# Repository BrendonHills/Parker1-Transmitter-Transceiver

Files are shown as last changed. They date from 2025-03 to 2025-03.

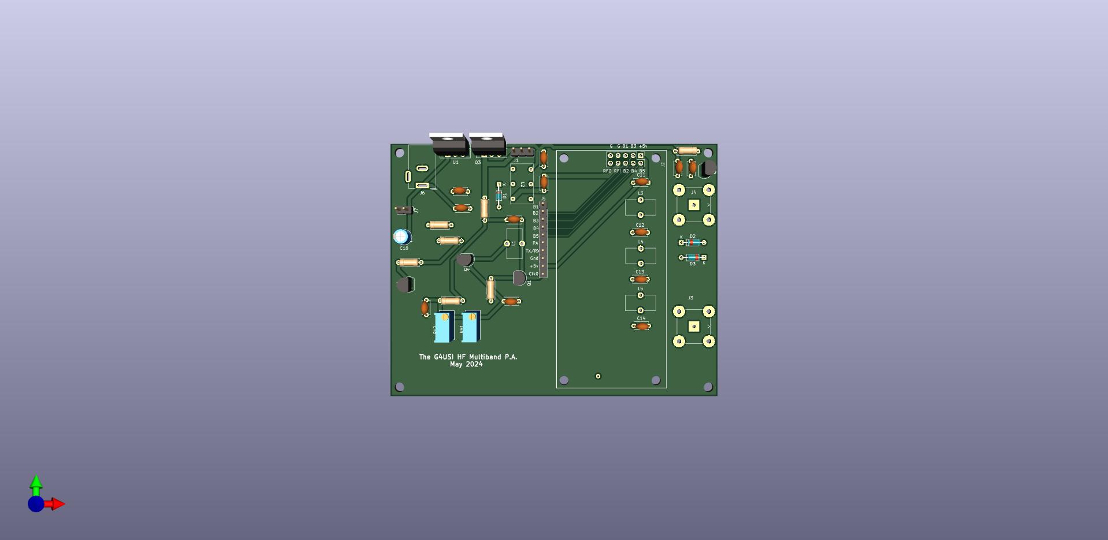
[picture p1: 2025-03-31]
HF PA multibandFront.jpg

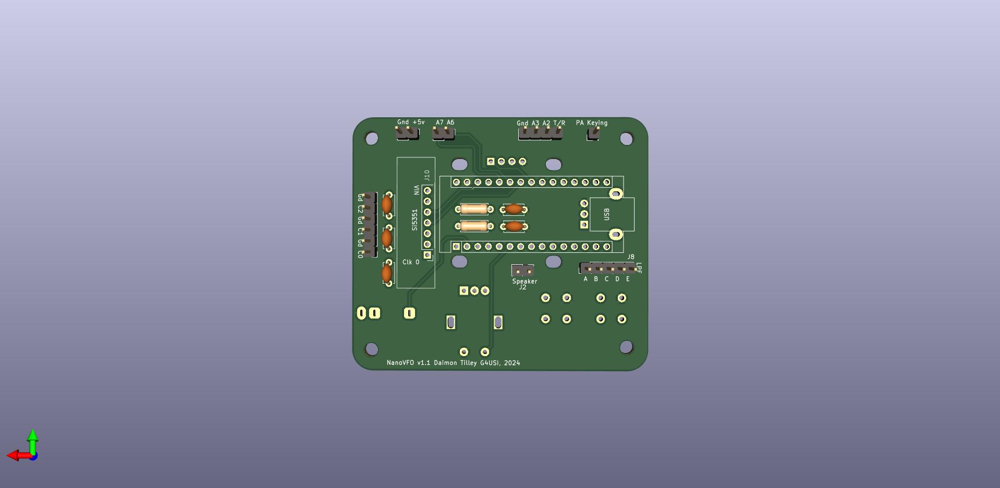
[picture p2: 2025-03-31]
NanoVFOpcbRear.jpg

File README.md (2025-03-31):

# The Parker1-Transmitter / Transceiver
The design of a ten band HF transmitter / transceiver and winner of the G-QRP Club Memorial Trophy 2024.

Please see the attached submission to the G-QRP Club for a full description of the project. Circuit diagrams and PCB files are in Ki-Cad 7.0
software and you may need to download that in order to view.

The transmitter consists of two parts, the Nano VFO and the HF Multi-band PA, connected together to make the transmitter. 
Note that the HF PA board is designed to have the QRPLabs LPF Relay board mounted on it to provide five LPFs covering ten bands (160-10m.)

Since this submission, the transmitter is now a transceiver, with the addition of a QRPLabs RX module, 
Hi-Per-Mite CW filter and audio amp. This is not protrayed in the diagrams here, but the circuit diagrams of the TX and VFO should make connections clear.
The L-Match ATU and internal battery pack are also not depicted, and there are no diagrams for this, but you should be able to work this out yourself.
All that is shown here is the code, circuit diagrams and PCB files for the VFO and for the PA board, nothing else,
however it is a great place to start and then experiment further.

I AM SORRY BUT I AM TOO BUSY TO OFFER SUPPORT OR ANSWER QUESTIONS (I have already answered a lot!) Please do not attempt this project without being
aware of that and reasonably confident in your abilities. My advice would to be just build the VFO first. The provided transceiver code will still work with just the VFO, but be aware that the code only activates the Si5351 clocks for TX and TX when those modes are in operation. In other words, to use just the VFO you would need to modify the clock output code to acheive a permanent clock / VFO output if that is what is required.

You will need to modify the code yourself to select your starting frequency and your callsign / CQ message. I have tried to make the code clear with plenty of remarks.
You will also need to amend the code to choose the RX frequency settings (i.e. offset, etc.) These options are NOT menu driven and must be done within the code
before uploading to the VFO. Therefore a degree of construction and programming experience is absolutely required.

The project has attracted quite a bit of interest since recently winning the G-QRP Club 2024 Construction Competition (G3RJV Trophy) and the intent
of this repository is to assist those interested in building it or using it as a platform for their own projects. I am sorry I am unable to help further but
hope this is of use.

Good luck.
Daimon, G4USI.

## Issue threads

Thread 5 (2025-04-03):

(Feature Request)- Create single document BOM for Parker1 Build

chrisdebian, 2025-04-03:
To help kit builders to compare local component prices, and to easily order items, the community should create a Bill of Materials (parts list) or BOM. Many examples exist of what to include in a BOM, and [this](https://www.proto-electronics.com/blog/how-to-create-best-bom-for-pcb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,could%20have%20a%20dedicated%20BOM.) is just one such example.

The file should be easily recognisable, including 'BOM-Bill of Materials' and any version numbers.

Chris
2E0FRU

chrisdebian, 2025-04-04:
I have found an example, [here](Example format from https://www.newburyelectronics.co.uk/news/free-bom-template-for-excel/). I can't upload this to the main project page, as I don't have 'push' access.

[pcb-bom-sample-file.xlsx](https://github.com/user-attachments/files/19602316/pcb-bom-sample-file.xlsx)

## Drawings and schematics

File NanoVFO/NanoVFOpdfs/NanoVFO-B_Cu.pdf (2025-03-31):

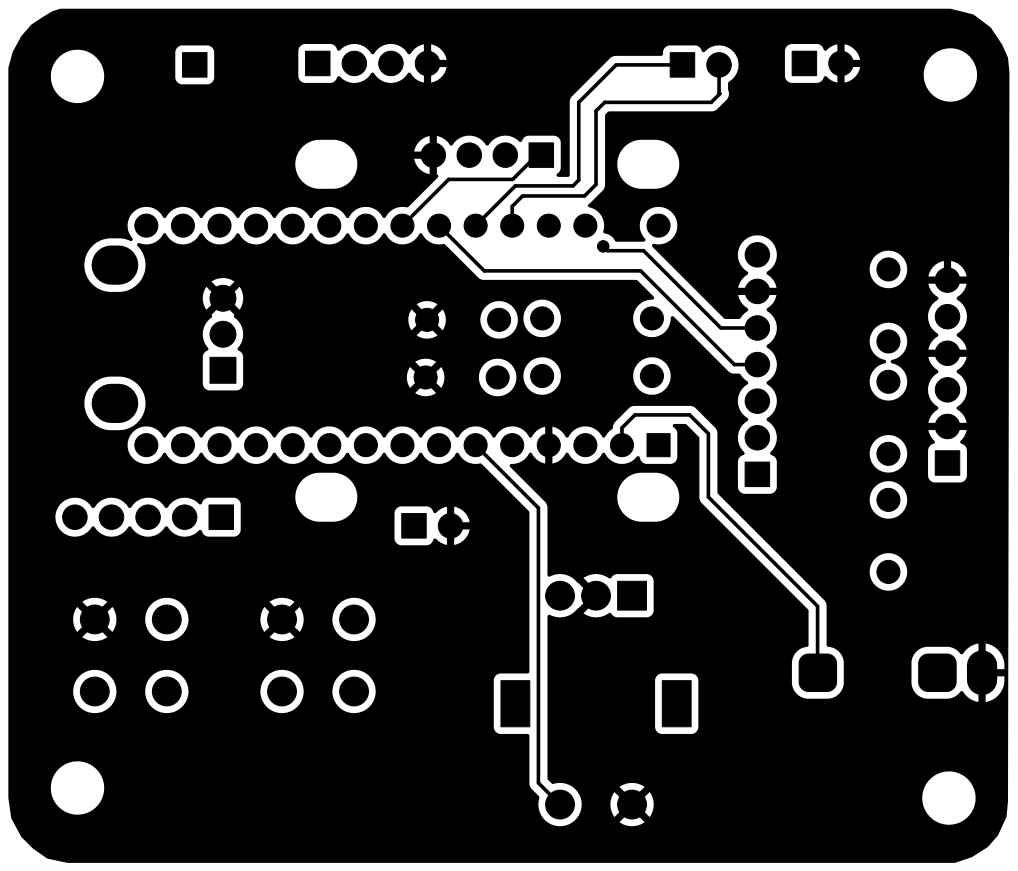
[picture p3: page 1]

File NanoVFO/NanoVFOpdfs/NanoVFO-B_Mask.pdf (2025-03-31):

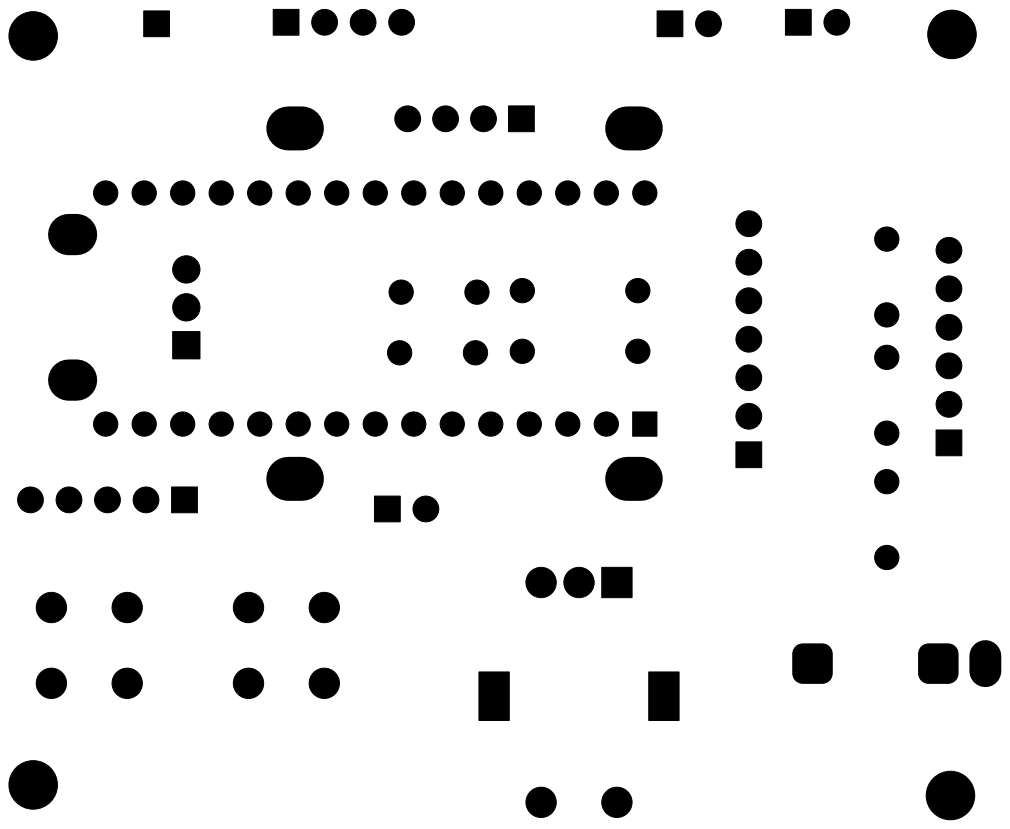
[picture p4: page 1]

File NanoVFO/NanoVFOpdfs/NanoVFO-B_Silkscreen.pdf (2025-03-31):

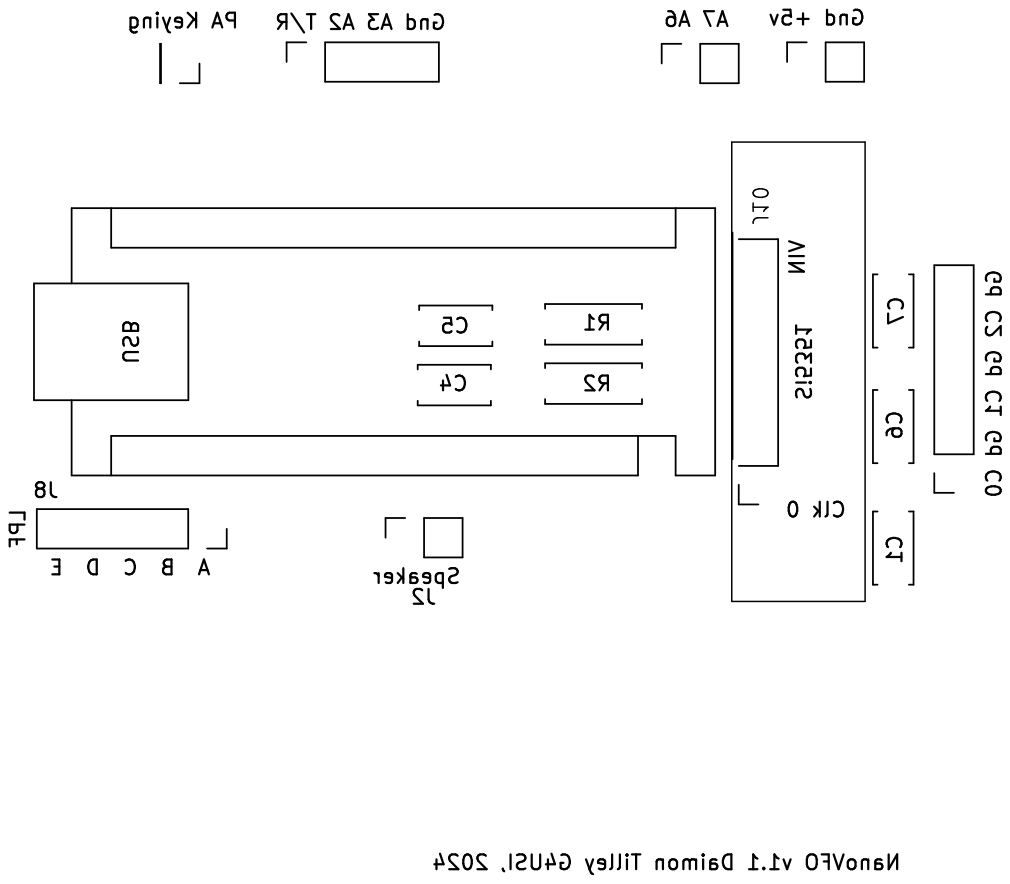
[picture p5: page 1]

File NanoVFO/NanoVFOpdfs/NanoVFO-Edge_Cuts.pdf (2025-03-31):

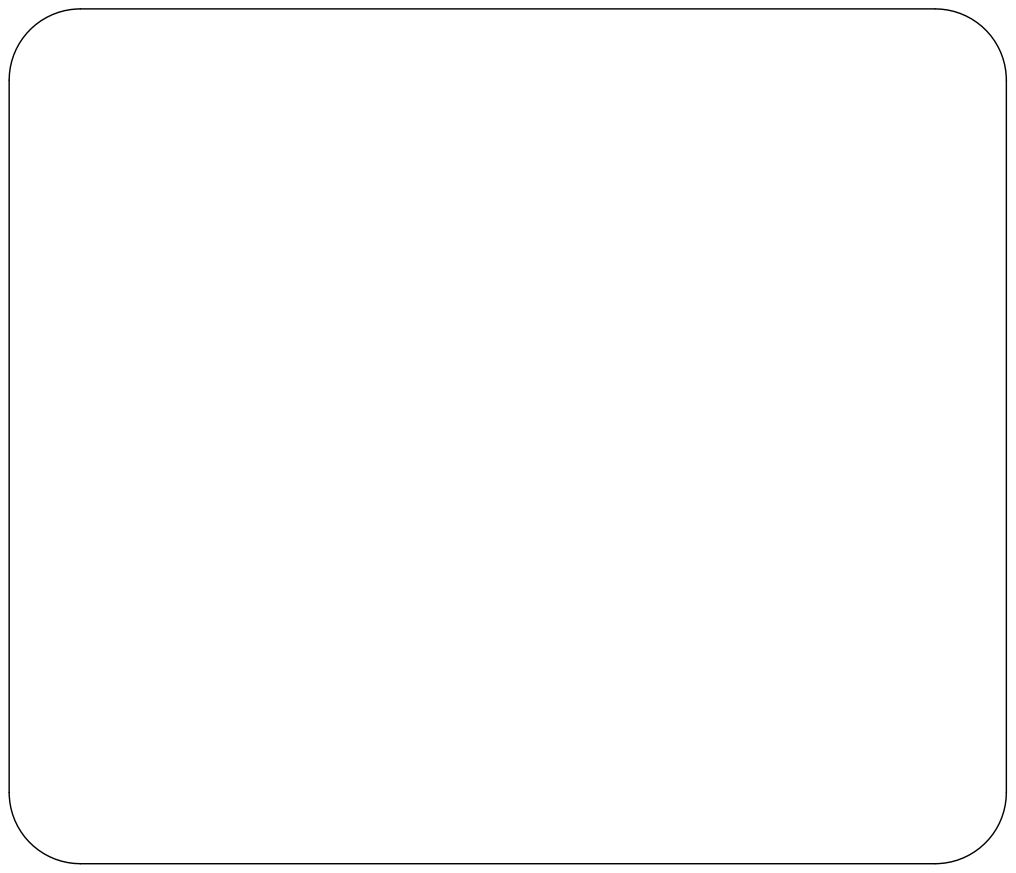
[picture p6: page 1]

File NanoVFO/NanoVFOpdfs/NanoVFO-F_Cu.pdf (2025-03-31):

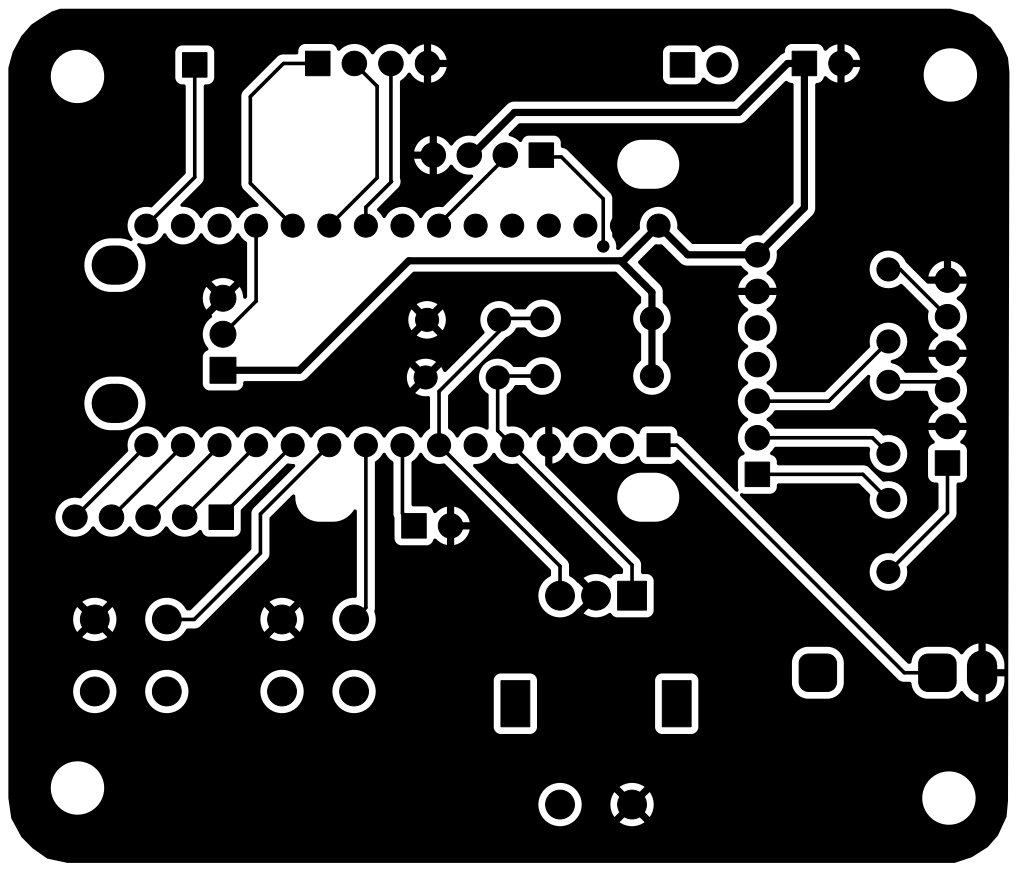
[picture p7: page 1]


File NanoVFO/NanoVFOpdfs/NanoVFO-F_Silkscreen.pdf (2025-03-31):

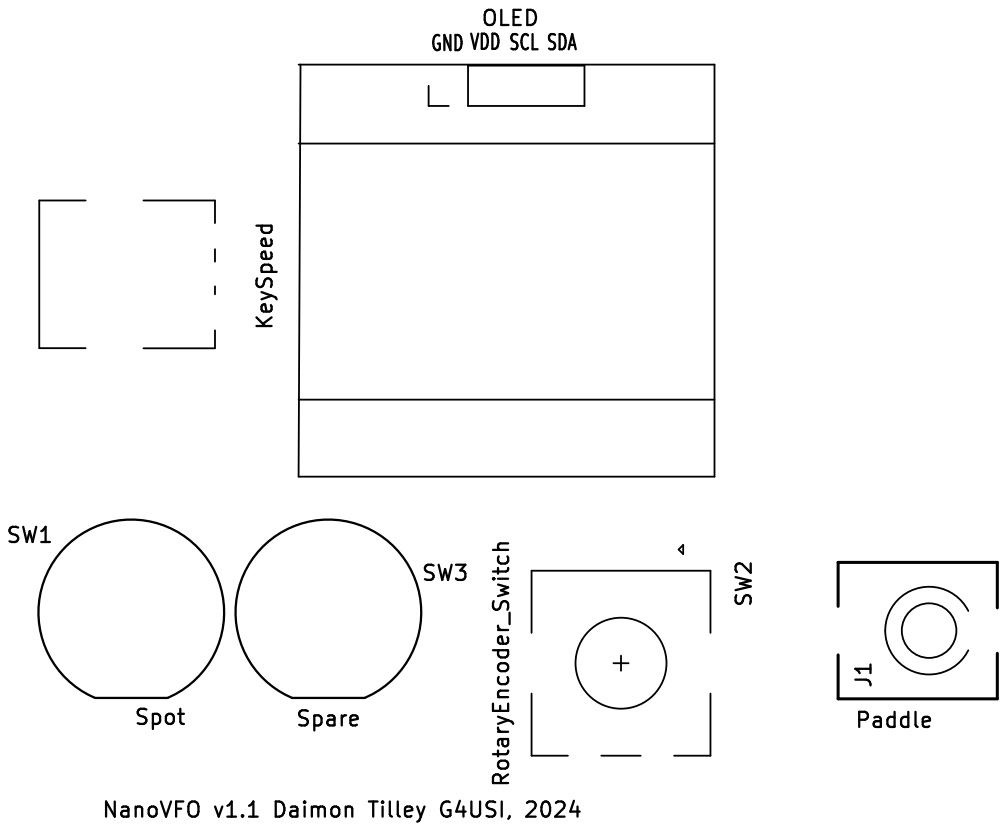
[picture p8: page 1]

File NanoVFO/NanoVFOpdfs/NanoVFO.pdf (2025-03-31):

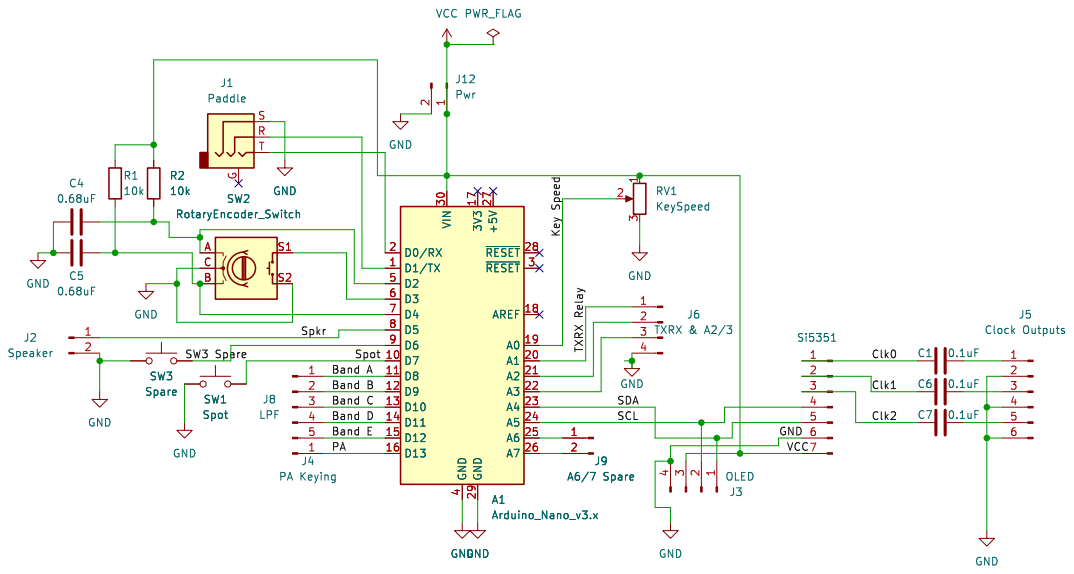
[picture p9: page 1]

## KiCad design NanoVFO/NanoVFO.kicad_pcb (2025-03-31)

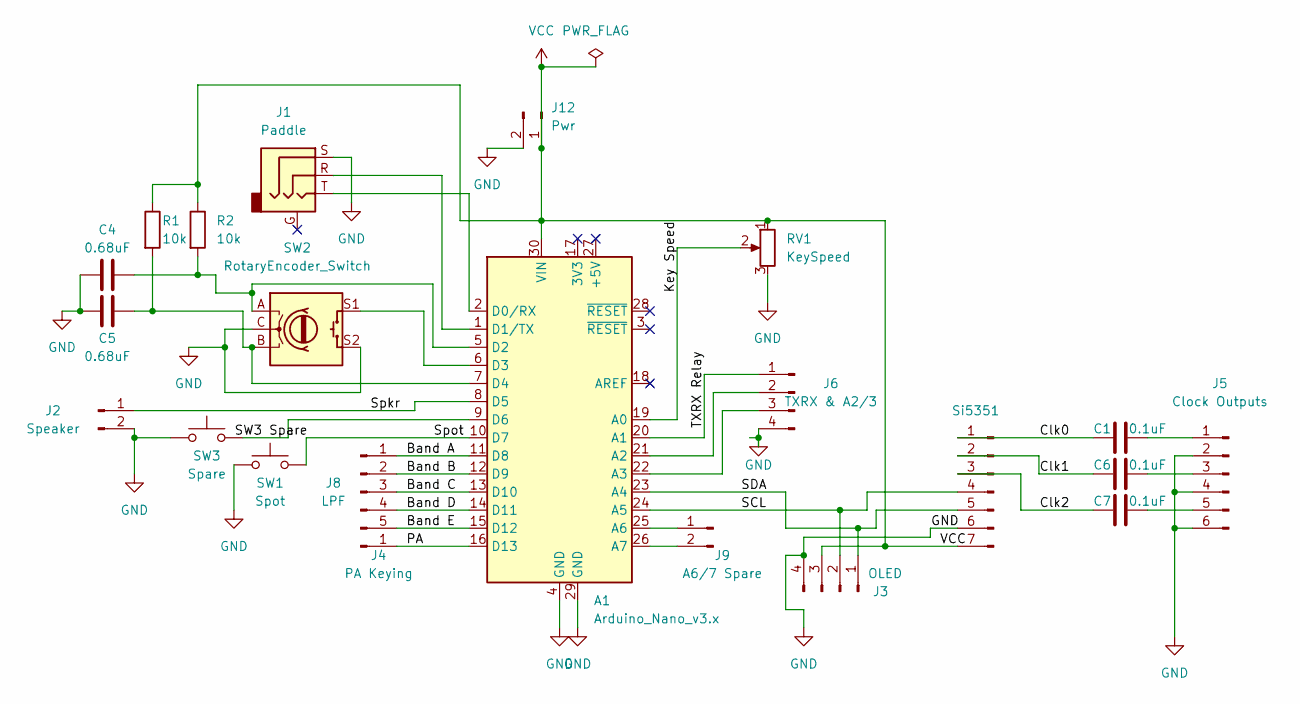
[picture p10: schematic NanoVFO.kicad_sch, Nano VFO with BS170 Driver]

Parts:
A1: Arduino_Nano_v3.x; Arduino_Nano
C1, C6, C7: 0.1uF; C_Disc_D4.7mm_W2.5mm_P5.00mm
C4, C5: 0.68uF; C_Disc_D4.7mm_W2.5mm_P5.00mm
J1: Paddle; Jack_3.5mm_QingPu_WQP-PJ366ST_Vertical
J2: Speaker; PinHeader_1x02_P2.54mm_Vertical
J3: OLED; Display_128x64_096_I2C
J4: PA Keying; PinHeader_1x01_P2.54mm_Vertical
J5: Clock Outputs; PinHeader_1x06_P2.54mm_Vertical
J6: TXRX & A2/3; PinHeader_1x04_P2.54mm_Vertical
J8: LPF; PinHeader_1x05_P2.54mm_Vertical
J9: A6/7 Spare; PinHeader_1x02_P2.54mm_Vertical
J10: Si5351; Si5351 Vertical
J12: Pwr; PinHeader_1x02_P2.54mm_Vertical
R1, R2: 10k; R_Axial_DIN0207_L6.3mm_D2.5mm_P7.62mm_Horizontal
RV1: KeySpeed; Potentiometer_Alpha_RD901F-40-00D_Single_Vertical
SW1: Spot; Push_E-Switch_KS01Q01
SW2: RotaryEncoder_Switch; RotaryEncoder_Alps_EC11E-Switch_Vertical_H20mm
SW3: Spare; Push_E-Switch_KS01Q01

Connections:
/Band A: A1.11 (D8), J8.1
/Band B: A1.12 (D9), J8.2
/Band C: A1.13 (D10), J8.3
/Band D: A1.14 (D11), J8.4
/Band E: A1.15 (D12), J8.5
/Clk0: C1.2, J10.1
/Clk1: C6.1, J10.2
/Clk2: C7.1, J10.3
/Key Speed: A1.19 (A0), RV1.2
/PA: A1.16 (D13), J4.1
/SCL: A1.24 (A5), J3.2, J10.4
/SDA: A1.23 (A4), J3.1, J10.5
/Spkr: A1.8 (D5), J2.1
/Spot: A1.10 (D7), SW1.2
/TXRX Relay: A1.20 (A1), J6.1
GND: A1.4 (GND), A1.29 (GND), C4.2, C5.2, J1.S, J2.2, J3.4, J5.2, J5.4, J5.6, J6.4, J10.6, J12.2, RV1.3, SW1.1, SW2.C, SW2.S2, SW3.1
unnamed: A1.21 (A2), J6.2
unnamed: A1.22 (A3), J6.3
unnamed: A1.25 (A6), J9.1
unnamed: A1.26 (A7), J9.2
unnamed: A1.2 (D0/RX), J1.T
unnamed: A1.1 (D1/TX), J1.R
unnamed: A1.5 (D2), C4.1, R2.2, SW2.A
unnamed: A1.6 (D3), SW2.S1
unnamed: A1.7 (D4), C5.1, R1.2, SW2.B
unnamed: A1.9 (D6), SW3.2
unnamed: C1.1, J5.1
unnamed: C6.2, J5.3
unnamed: C7.2, J5.5
VCC: A1.30 (VIN), J3.3, J10.7, J12.1, R1.1, R2.1, RV1.1

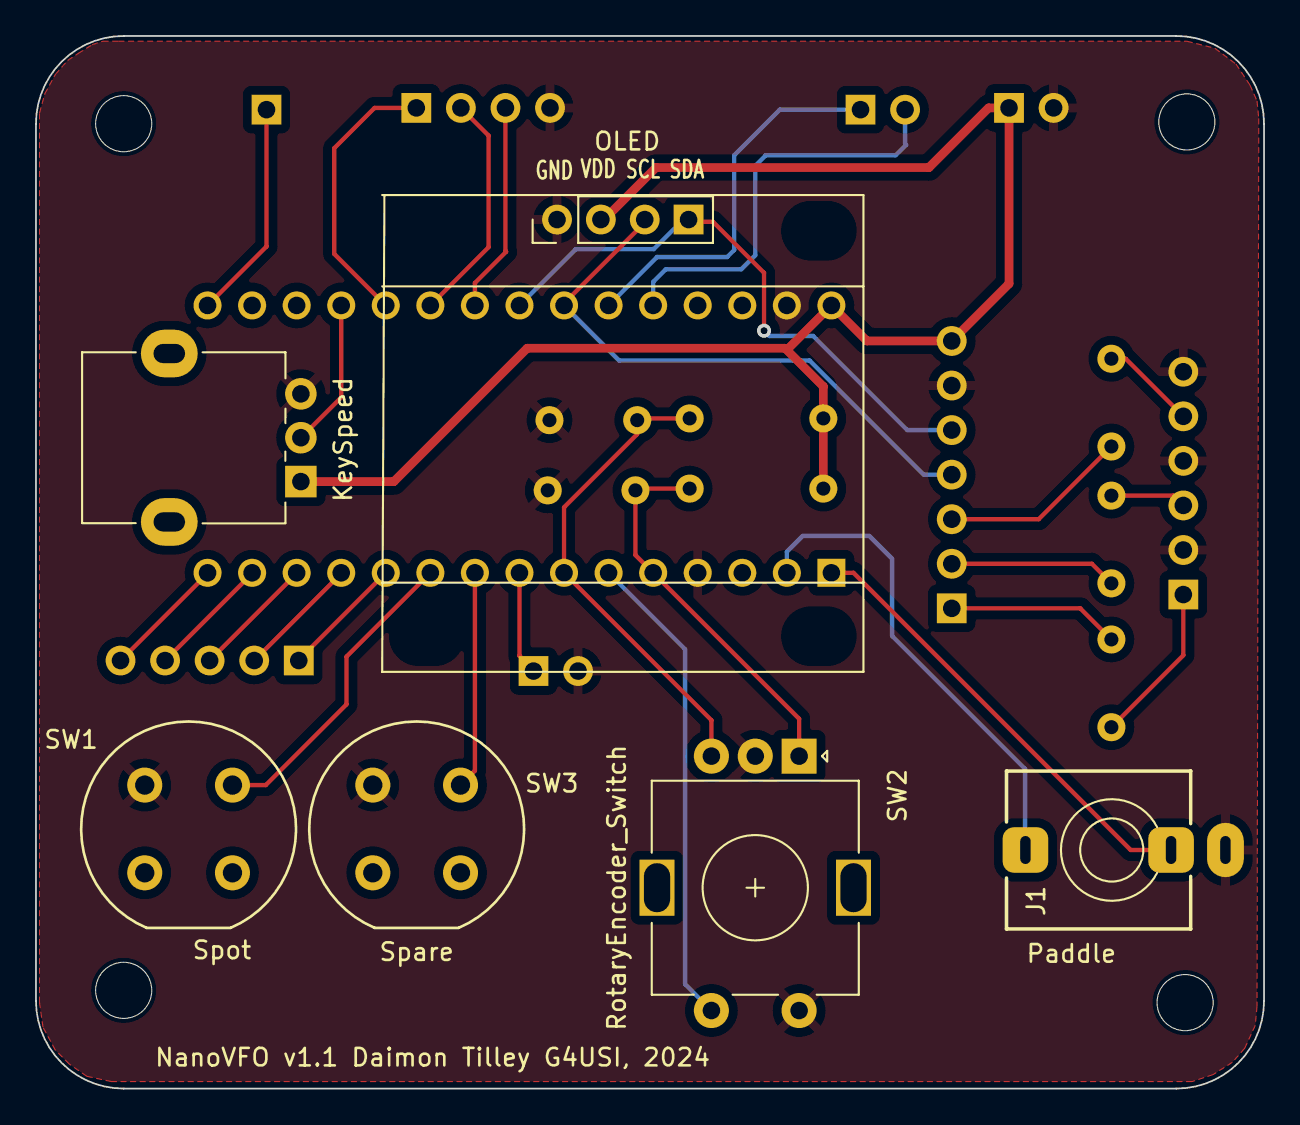
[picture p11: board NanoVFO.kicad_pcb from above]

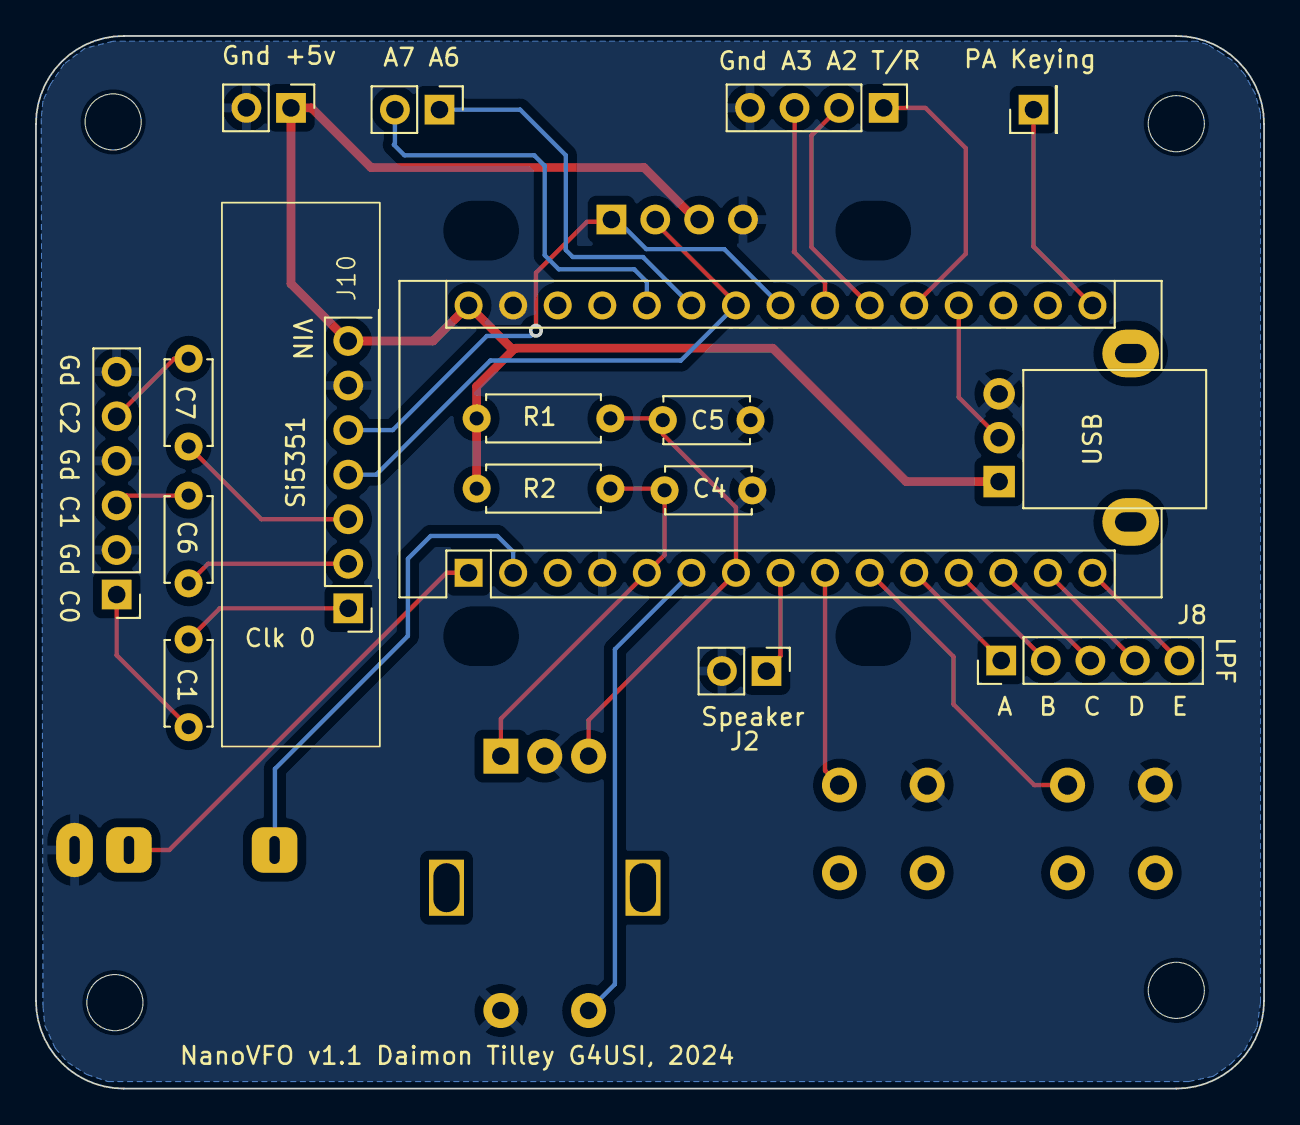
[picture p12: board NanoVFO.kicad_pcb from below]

Board: 2 copper layers, 70.0 x 60.0 mm, 22 parts (16 on the bottom side), 30 nets.

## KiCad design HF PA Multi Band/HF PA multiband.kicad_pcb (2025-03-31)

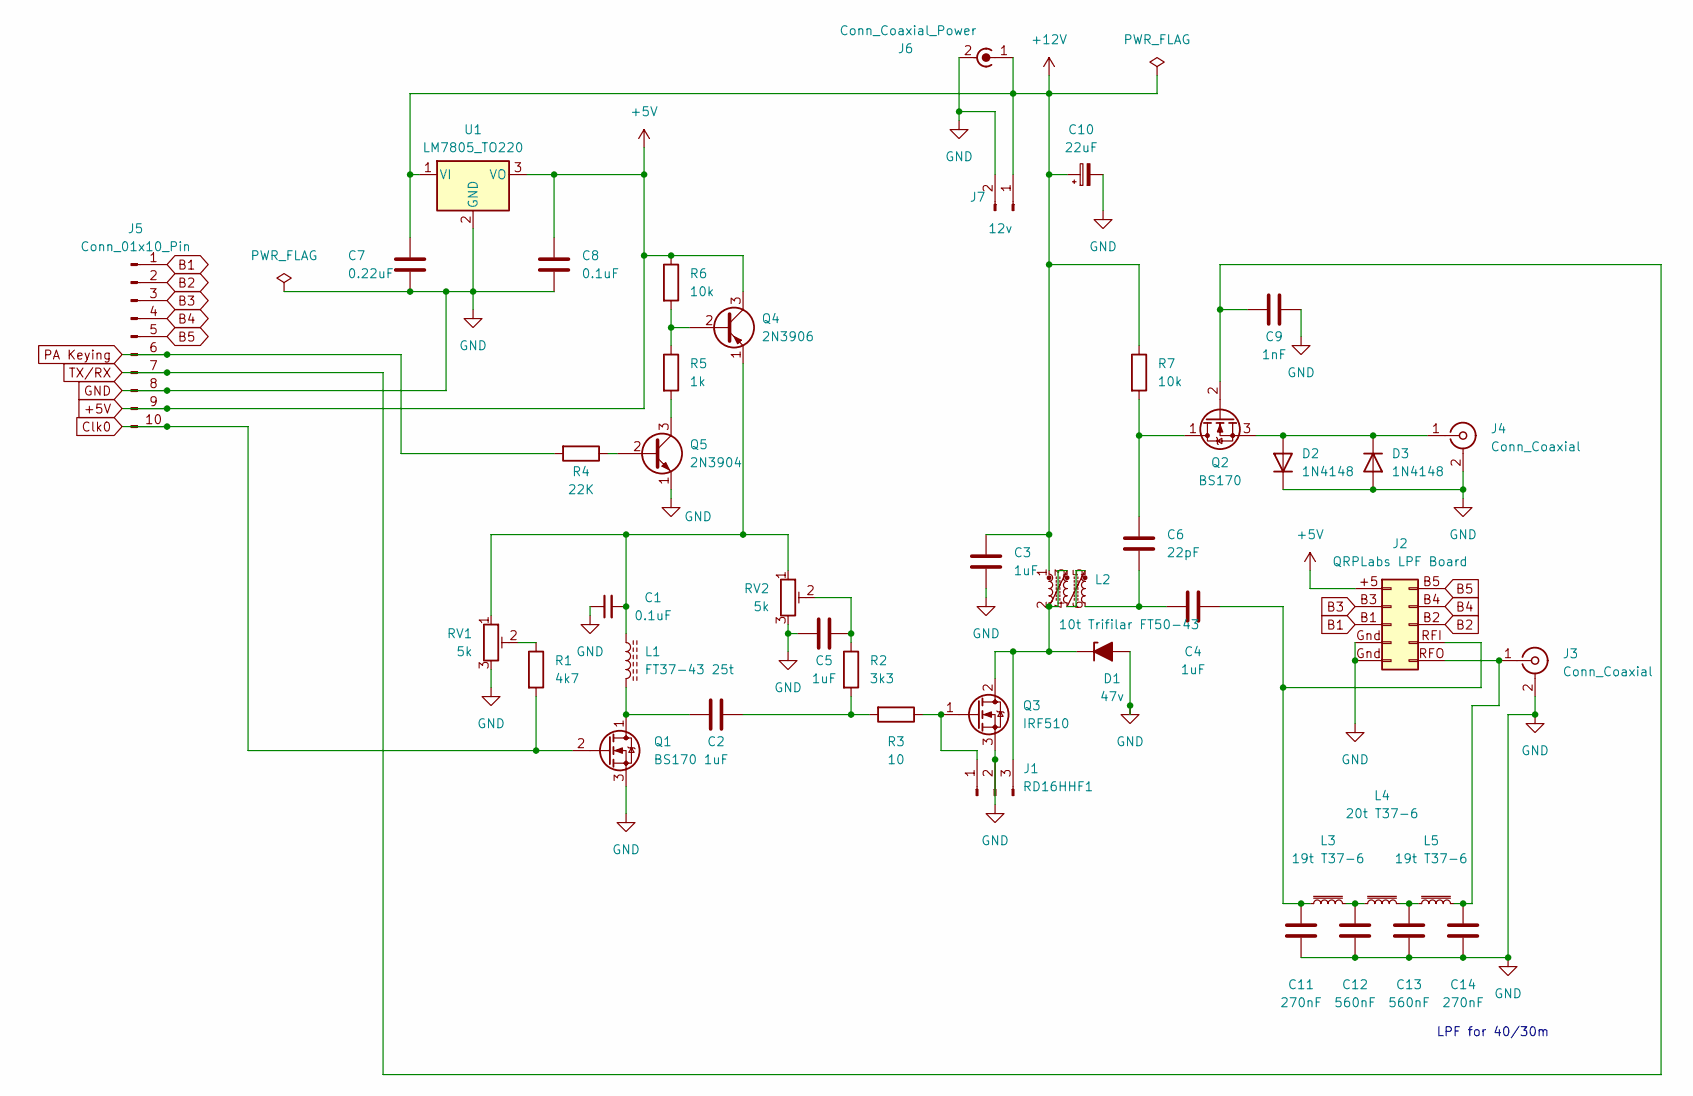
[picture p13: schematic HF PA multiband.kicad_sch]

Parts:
C1, C8: 0.1uF; C_Disc_D4.7mm_W2.5mm_P5.00mm
C2, C3, C4, C5: 1uF; C_Disc_D4.7mm_W2.5mm_P5.00mm
C6: 22pF; C_Disc_D4.7mm_W2.5mm_P5.00mm
C7: 0.22uF; C_Disc_D4.7mm_W2.5mm_P5.00mm
C9: 1nF; C_Disc_D4.7mm_W2.5mm_P5.00mm
C10: 22uF; CP_Radial_D5.0mm_P2.00mm
C11, C14: 270nF; C_Disc_D4.7mm_W2.5mm_P5.00mm
C12, C13: 560nF; C_Disc_D4.7mm_W2.5mm_P5.00mm
D1: 47v; D_DO-34_SOD68_P7.62mm_Horizontal
D2, D3: 1N4148; D_DO-35_SOD27_P7.62mm_Horizontal
J1: RD16HHF1; PinHeader_1x03_P2.54mm_Vertical
J2: QRPLabs LPF Board; QRPLabs LPF Relay Board
J3, J4: Conn_Coaxial; BNC_TEConnectivity_1478035_Horizontal
J5: Conn_01x10_Pin; PinHeader_1x10_P2.54mm_Vertical
J6: Conn_Coaxial_Power; BarrelJack_Wuerth_6941xx301002
J7: 12v; PinHeader_1x02_P2.54mm_Vertical
L1: FT37-43 25t; L_Toroid_Vertical_L10.0mm_W5.0mm_P5.08mm
L2: 10t Trifilar FT50-43; L_Trifilar_FT50_43
L3, L5: 19t T37-6; L_Toroid_Vertical_L10.0mm_W5.0mm_P5.08mm
L4: 20t T37-6; L_Toroid_Vertical_L10.0mm_W5.0mm_P5.08mm
Q1, Q2: BS170; TO-92_Inline
Q3: IRF510; TO-220-3_Vertical
Q4: 2N3906; TO-92_Inline
Q5: 2N3904; TO-92_Inline
R1: 4k7; R_Axial_DIN0207_L6.3mm_D2.5mm_P7.62mm_Horizontal
R2: 3k3; R_Axial_DIN0207_L6.3mm_D2.5mm_P7.62mm_Horizontal
R3: 10; R_Axial_DIN0207_L6.3mm_D2.5mm_P7.62mm_Horizontal
R4: 22K; R_Axial_DIN0207_L6.3mm_D2.5mm_P7.62mm_Horizontal
R5: 1k; R_Axial_DIN0207_L6.3mm_D2.5mm_P7.62mm_Horizontal
R6, R7: 10k; R_Axial_DIN0207_L6.3mm_D2.5mm_P7.62mm_Horizontal
RV1, RV2: 5k; Potentiometer_Bourns_3296W_Vertical
U1: LM7805_TO220; TO-220-3_Vertical

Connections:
+5V: C8.1, J2.+5 (Pin_1), J5.9, Q4.3 (C), R6.1, U1.3 (VO)
+12V: C3.1, C7.1, C10.1, J6.1 (In), J7.1, L2.1, R7.1, U1.1 (VI)
B1: J2.B1 (Pin_3), J5.1
B2: J2.B2 (Pin_8), J5.2
B3: J2.B3 (Pin_2), J5.3
B4: J2.B4 (Pin_9), J5.4
B5: J2.B5 (Pin_10), J5.5
Clk0: J5.10, Q1.2 (G), R1.2
GND: C1.1, C3.2, C5.2, C7.2, C8.2, C9.2, C10.2, C11.2, C12.2, C13.2, C14.2, D1.2 (A), D2.1 (K), D3.2 (A), J1.2, J2.Gnd (Pin_4), J3.2 (Ext), J4.2 (Ext), J5.8, J6.2 (Ext), J7.2, Q1.3 (S), Q3.3 (S), Q5.1 (E), RV1.3, RV2.3, U1.2 (GND)
unnamed: C2.1, R2.2, R3.2
unnamed: C4.2, C6.2, L2.6
unnamed: C5.1, R2.1, RV2.2
unnamed: C12.1, L3.2, L4.1
unnamed: C13.1, L4.2, L5.1
unnamed: D1.1 (K), J1.3, L2.2, L2.3, Q3.2 (D)
unnamed: D2.2 (A), D3.1 (K), J4.1 (In), Q2.3 (S)
unnamed: J1.1, Q3.1 (G), R3.1
unnamed: C14.1, J2.RFO (Pin_6), J3.1 (In), L5.2
unnamed: C4.1, C11.1, J2.RFI (Pin_7), L3.1
unnamed: L2.4, L2.5
unnamed: C2.2, L1.2, Q1.1 (D)
unnamed: C6.1, Q2.1 (D), R7.2
unnamed: Q4.2 (B), R5.1, R6.2
unnamed: C1.2, L1.1, Q4.1 (E), RV1.1, RV2.1
unnamed: Q5.2 (B), R4.1
unnamed: Q5.3 (C), R5.2
unnamed: R1.1, RV1.2
PA Keying: J5.6, R4.2
TX/RX: C9.1, J5.7, Q2.2 (G)

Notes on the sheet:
LPF for 40/30m

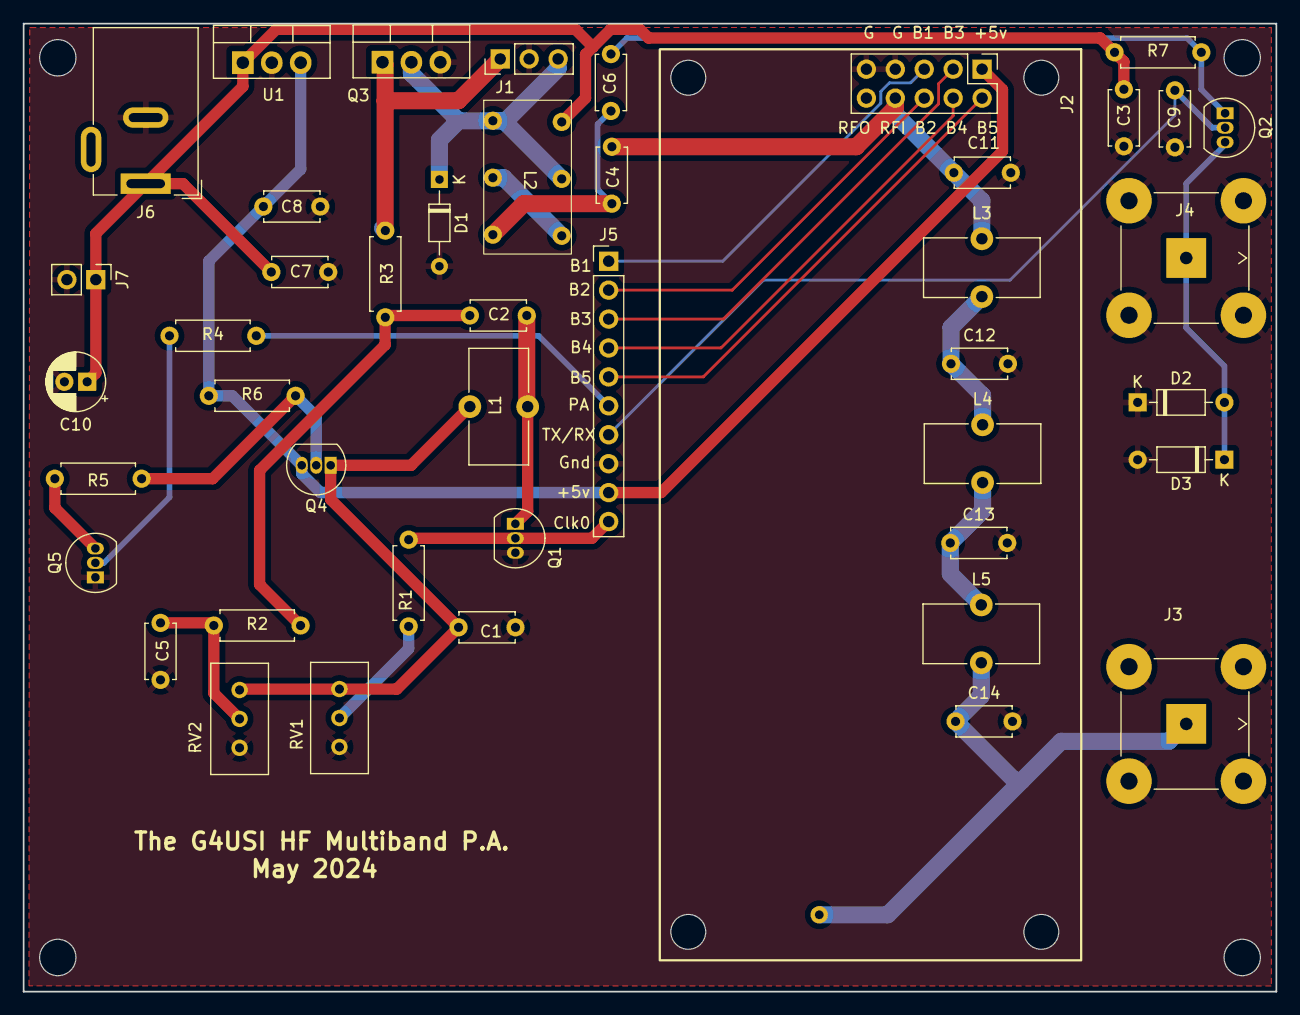
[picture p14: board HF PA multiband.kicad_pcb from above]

Board: 2 copper layers, 110.0 x 85.0 mm, 44 parts (0 on the bottom side), 29 nets.

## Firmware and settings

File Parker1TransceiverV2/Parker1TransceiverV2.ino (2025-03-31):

/*
  ==================================================
   The Parker1 Transceiver by Daimon Tilley, G4USI. 
  ==================================================
      standing on the shoulders of:
      The Tuna Tin S by Bob Fontana AK3Y, as amended by Carol Milazzo KP4MD.
      Their code was the basis of this code, but I have changed it very substantially. All
      that remains of their original code is aspects of the display, encoder menu and band array functions.

  Revised 8/2/25 by Daimon Tilley, G4USI - Improved the CQ memory, such that it repeats every 4 seconds until left paddle or straight key is pressed
  Revised 3/2/2025 by Daimon Tilley, G4USI - Improved and simplified Sidetone code for a 700Hz tone and improved key speed detection.
  Revised 30/1/25 by Daimon Tilley, G4USI - THE PARKER 1 IS NOW A FULL 10 BAND TRANSCEIVER! IT ALSO WON THE 2024 G-QRP CLUB CONSTRUCTION COMPETITION!!!!
    -- Clock 2 now enables as Quadrature output for integrated QRPLabs RX module. 
    -- Changed Si5351 library from Etherkit to Si5351mcu to remove clicks from receiver on encoder movement
    -- Hardware changes include adding QRPLabs RX module, a Hi-Per-Mite CW filter, Audio Amp and feeding CW sidetone
       into the audio filter. Also added a volume control, Wide/Narrow switch to bypass filter and send RX audio direct to amplifier
       and finally included a headphone jack. 
  Revised 10/7/24 by Daimon Tilley, G4USI - rig now completed and boxed.
    -- Added to the display with a supply voltage display using Pin A2 and a 20k/10k voltage divider
    -- Added to the display with a readout of the Keyer WPM setting
  Revised 1/7/24 by Daimon Tilley, G4USI as a 160-10m Portable Transmitter with battery and L-Match ATU,
    -- Corrected Spot / Key switches
    -- Turned off internal RX clock
  Revised 14/3/2024 by Daimon Tilley, G4USI - Vers. 2.1
    -- Amended use of CW OUT pin to use to activate PNP transistor as High Side switch on 5v PA bias supply.
       This pin is now kept HIGH on RX to switch this transistor off. On TX pin is pulled LOW to provide bias supply.
  Revised 9/3/2024 by Daimon Tilley, G4USI - Vers. 2.0
    -- Bugfix to frequency setting which prevented sinewave! (SetFreq increased *100ULL).
  Revised 23/2/24 by Daimon Tilley, G4USI - Vers 1.9
    -- During automated CQ call, pressing the dit lever, or external or internal straight key 
      will cease the auto CQ. NOTE however, that this is not done using an interrupt pin, 
      so the key must be held so it is recognised as closed between characters. 
      A slower auto CQ will require the key to be held closed for longer than a faster one. 
      In practice this is fine.
    -- Added a welcome-beep on power up
  Revised 20/2/24 by Daimon Tilley, G4USI - Vers 1.8
    -- Reduced code by 14 lines by creating two new functions - enableTX() and enableRX()
  Revised 20/2/24 by Daimon Tilley, G4USI - Vers 1.7
    -- Amended to remove the 630m and 6m bands
    -- LPF filters adjusted to match and are now grouped as follows:
        160m          - Pin 8
        80 / 60m      - Pin 9
        40 / 30m      - Pin 10
        20 / 17m      - Pin 11
        15/12/10m     - Pin 12
        All pins HIGH except for band in use which is LOW
  Revised 20/2/24 by Daimon Tilley, G4USI - Vers 1.6
    -- Amended to recognise both short and long press of Rotary Encoder -
       - Short press (<1 secs) functions as before (Frequency and Band Steps)
       - Long press (>1 secs) AND release of encoder now initiates stored CW CQ message
       - Spare button now reverts to internal straight key
  Revised 19/2/24 by Daimon Tilley, G4USI - Vers 1.5
    -- Removed keying code from PA3HCM and added simple memory keyer, based on CW Beacon by K6HX 
        but significantly amended to allow variable speeds set by SpeedPot and amended to work with paddle, 
        a straight key and a memory button.
        Spare key use changed from internal straight key to CW message send
  Revised 19/2/24 by daimon Tilley, G4USI - Vers 1.4
    -- Spot and Spare buttons on 3d printed fascia were wrong, so now amended to Spot = 6 and Spare = 7. 
    -- Spare button on PCB now acts as internal straight key for emergency / no external key available
  Revised 18/2/24 by Daimon Tilley, G4USI - Vers 1.3
    -- Amended so that band change relay switching occurs only when band selected, rather than changing when cycling through bands
    -- Amended so that after a band change occurs, tuning step default is 100Hz
    -- Recognises if straight key plugged in at start-up and if so, omits keying software. If you wish to change to paddle,
        then power down, plug in paddle and re-boot, and vice verca. There is no option to change from software. Straight key recognition
        or otherwise occurs just once in setup on booting. A straight key must be wired to a mono audio jack plug for this to work.
  Revised 18/2/24 by Daimon Tilley, G4USI - Vers. 1.2
    -- Re-named NanoVFO to reflect bespoke VFO PCB
    -- Added Clk2 for RX with options for either 700Hz positive offset or 4x freq + 700Hz for Quadrature RX, i.e. QRPLabs RX module
    -- Removed EEPROM facility as not required
    -- Removed alternate Freq Step indication as uneccessary
  Revised 10/2/24 by Daimon Tilley, G4USI
    -- Improved reading of key speed pot
   Revised 1/12/23 by Daimon Tilley, G4USI
     -- Replaced Adafruit Si5351 library and associated code, with Etherkit library and code to simplify code and maths
   Revised 10/7/23 by Daimon Tilley, G4USI
     -- Added simple CW keying code, based on code by PA3HCM
     -- Added sidetone from Pin 5 (Just connect speaker between Pin5 and Gnd - use a 120 ohm resistor to limit current)
   Revised 13/5/23 by Daimon Tilley, G4USI
    -- Amended start-up frequency step to 0.1kHz
    -- Amended Transmit/Receive Pin from Pin 8 to Pin 7
    -- Enable switching of QRP Labs LPF relay kit, allowing 5 bands (in my case 160-20m inclusive) to
        be switched from band changes, by enabling Pins 8 - 12 respectively. Pin is HIGH to turn off relays
        and LOW to activate the correct relay for the band.
   Revised 12/5/23 by Daimon Tilley G4USI
     -- Physically changed board layout to allow PTT line-out switching
   Revised 12/3/2022 by Daimon Tilley G4USI
     -- amended dial correction factor and fixed a 60m channel mis-type
   Revised 25/2/2022 by Daimon Tilley G4USI
     -- amended 60m Channels for UK use
     -- amended QRP calling channels for IARU Region 1
   Revised 01 January 2022 by Carol Milazzo KP4MD
     -- added 630m & 6m
     -- cleaned up code and moved band constants into arrays
     -- new PLL constants improve freq tracking on 60m and 12m
   Revised 15 April 2021 by Carol Milazzo KP4MD
     -- added 160m, 17m and 12m
     -- corrected Calibration Offset for all bands
   Revised 09 April 2021 by Carol Milazzo KP4MD
     -- added default QRP frequencies and band switching for 80, 40, 60, 30, 20, 15 and 10 meters
     -- added band indicator to display
   Revised 27 March 2021 Revisions below by Bob Fontana AK3Y
     -- added provision for 5 fixed frequency CW channels on 60 meters
     -- fixed EEProm code so that header changes to Band will trigger rewrite
   Revised 24 February 2021
     -- added timing loop to EEPROM write; current settings will not be written to nonvolatile
     -- memory until DELAY_TIME has been exceeded.  This prevents too many writes to EEPROM which
     -- can only handle around 100,000 writes
   Revised 21 February 2021
     -- added EEPROM storage of last used frequency and tuning rate (loads upon reboot)
     -- Note: if only tuning rate is changed, data is not stored
   Revised 12 December 2020
     -- added an additional tuning increment (10Hz, 100Hz and 1000Hz)
     -- pressing switch toggles from 1000 --> 100 --> 10 --> 1000 Hz
   Revised 10 December 2020
     -- added 30 meters to frequency bands
     -- modified display to indicate tuning rate
   Revised 3 March 2020 -- added Transmit/Receive function to kill synthesizer output on Receive
   Revised 25 February 2020 -- added Calibration Offset
     -- Note: calibration offset should be computed for each band of operation

   12 February 2020
*/

#include <Wire.h>              // Include I2L Library for Communications with OLED Display and Synthesizer
//#include <si5351.h>            // Include Etherkit library
#include "si5351mcu.h"
#include <Adafruit_SSD1306.h>  // Include OLED Display Library

#define SCREEN_WIDTH 128  // OLED display width, in pixels
#define SCREEN_HEIGHT 32  // OLED display height, in pixels
#define XT_CAL_F 0     //++++++Si5351 calibration factor, adjust to get exatcly 10MHz. Starts at 330000 ++++ Increasing this value will decreases the frequency and vice versa.

//CW Keyer==========================================================================================================================================
const int paddleDot = 0;    // Connects to the dot lever of the paddle
const int paddleDash = 1;   // Connects to the dash lever of the paddle
const int sidetonePin = 5;  // Audio output
const int biasPin = 13;     // Activates PNP transistor as High side swith to apply +5v bias to PA
const int switchPin = A1;   // To activate TX / RX relay
const int intKey = 7;       // Using "Spare" button on pcb as internal straight key
int keySpeed = A0;          // Attached to center pin of potmeter, allows you to set the keying speed.
int speed;                  // Converts Speed Pot reading to a WPM value
int voltageDivider;         // Reads one third of the supply voltage via a 20k / 10k voltage divider
float voltage;              // Converts the voltage divider reading to actual voltage for display
bool straightKey = false;   //Used to store flag to identify if straight key used at start up

//For memory / beacon function ===================================================================================================================
const int timeInterval = 4000;
unsigned long timeNow = 0;
struct t_mtab {
  char c, pat;
};

struct t_mtab morsetab[] = {
  { '.', 106 },
  { ',', 115 },
  { '?', 76 },
  { '/', 41 },
  { 'A', 6 },
  { 'B', 17 },
  { 'C', 21 },
  { 'D', 9 },
  { 'E', 2 },
  { 'F', 20 },
  { 'G', 11 },
  { 'H', 16 },
  { 'I', 4 },
  { 'J', 30 },
  { 'K', 13 },
  { 'L', 18 },
  { 'M', 7 },
  { 'N', 5 },
  { 'O', 15 },
  { 'P', 22 },
  { 'Q', 27 },
  { 'R', 10 },
  { 'S', 8 },
  { 'T', 3 },
  { 'U', 12 },
  { 'V', 24 },
  { 'W', 14 },
  { 'X', 25 },
  { 'Y', 29 },
  { 'Z', 19 },
  { '1', 62 },
  { '2', 60 },
  { '3', 56 },
  { '4', 48 },
  { '5', 32 },
  { '6', 33 },
  { '7', 35 },
  { '8', 39 },
  { '9', 47 },
  { '0', 63 }
};
#define N_MORSE (sizeof(morsetab) / sizeof(morsetab[0]))

int DOTLEN;
int DASHLEN;

// for LPF switching ==========================================================================================================================
bool bandChanged = false;  //flag if band changed
const int Pin160m = 8;     // selects appropriate relay board pin
const int Pin80m = 9;
const int Pin40m = 10;
const int Pin20m = 11;
const int Pin15m = 12;


// KY040 Rotary Encoder Module connections and variables ========================================================================================
const int PinCLK = 2;               // CLOCK (Interrupt line)  IMPORTANT! Decouple Pins 2 and 4 with 0.68uF caps to ground
const int PinSW = 3;                // Push Button Switch
const int PinDT = 4;                // Encoder DT Signal
const int SHORT_PRESS_TIME = 1000;  // 1 second
const int LONG_PRESS_TIME = 1000;   // 1 second
int lastState = HIGH;               // the previous state from the input pin
int currentState = HIGH;            // the current reading from the input pin
unsigned long pressedTime = 0;
unsigned long releasedTime = 0;

// Spot button ==================================================================================================================================
const int SPOT_Pin = 6;  // Add SPOT facility by turning on Si5351 but not keying PA stage

/* =============================================================================================================================================
    Define Bands of Operation, Initial Frequencies and Calibration Offset, if set
    NOTE: For 60 meters, there are only 5 frequencies allowable for the CW carrier
      5332, 5348, 5358.5, 5373 and 5405 kHz
      To start up for the first time on the nth channel, set Freq1 = n and Band = 60
      The Rotary Encoder will now be used to cycle through the 5 channels
      The push button steps through band switching and frequency step size
*/
// Define Frequency Bands - Band 0 is reserved for future use
int BandArray[11] = { 0, 160, 80, 60, 40, 30, 20, 17, 15, 12, 10 };
int LPFPinArray[11] = { 0, 8, 9, 9, 10, 10, 11, 11, 12, 12, 12 };  //+++++for LPF Filter Pins.
// Default QRP Calling Frequencies - 60m is Channel 4 but default to 1 as only 4 channels
long FreqArray[11] = { 0, 1836000, 3560000, 1, 7030000, 10116000, 14060000, 18086000, 21060000, 24906000, 28060000 };
long ChanArray[6] = { 0, 5259000, 5260000, 5261000, 5262000, 5263000 };
long cal = XT_CAL_F;

int Band = 4;                  // Initializes to 40m on startup - the "0" in BandArray does not count!
long Freq1 = FreqArray[Band];  // Initializes to QRP Calling frequency/Channel on the startup Band
int deltaFreq = 100;           // Initialize tuning rate to 100Hz (use 1 for 60 meter operation)

long oldFreq = 0;
int SPOT_State = 0;  //for SPOT switch

Si5351mcu Si;
Adafruit_SSD1306 display(SCREEN_WIDTH, SCREEN_HEIGHT, &Wire, 4);

//==============================================================================================================================================
void isr() {  // Interrupt Service Routine runs if Rotary Encoder CLK pin falls
  static unsigned long lastInterruptTime = 0;
  unsigned long interruptTime = millis();
  if (interruptTime - lastInterruptTime > 5) {

    if (!digitalRead(PinDT)) {  // If encoder rotated CCW

      if (deltaFreq == 0) {  // If deltaFreq is zero, save Freq1 and decrement Band
        FreqArray[Band] = Freq1;
        Band -= 1;
        if (Band < 1) Band = 10;
        Freq1 = FreqArray[Band];  // Load saved Freq1 for new band
        bandChanged = true;       //Set flag to indicate band has changed
      } else {                    // If deltaFreq is not zero
        if (Band == 3) {          // If Band is 60m decrement Channel
          Freq1 -= 1;
          if (Freq1 < 1) Freq1 = 5;
        } else Freq1 -= deltaFreq;  // If Band is not 60m decrement Frequency
      }
    } else {  // If encoder rotated CW

      if (deltaFreq == 0) {  // If deltaFreq is zero, save Freq1 and increment Band
        FreqArray[Band] = Freq1;
        Band += 1;
        if (Band > 10) Band = 1;
        Freq1 = FreqArray[Band];  // Load saved Freq1 for new band
        bandChanged = true;       //Set flag to indicate band has changed
      } else {                    // If deltaFreq is not zero
        if (Band == 3) {          // If Band is 60m increment Channel
          Freq1 += 1;
          if (Freq1 > 5) Freq1 = 1;
        } else Freq1 += deltaFreq;  // If Band is not 60m increment Frequency
      }
    }
  }
  lastInterruptTime = interruptTime;
}
//==============================================================================================================================================
void Splash()  // Splash screen displayed at power on/reset
{
  const char* text1 = "The Parker 1 Tcvr";
  const char* text2 = "160 - 10m by G4USI";
  const char* text3 = "2024 G-QRP Winner";

  display.clearDisplay();  // Clears the graphics display buffer.
  display.setTextSize(1);
  display.setTextColor(WHITE);

  display.setCursor(display.width() / 2 - strlen(text1) * 6 / 2, 0);  // Each character is approximately 6 pixels wide in default type font
  display.println(text1);
  display.setCursor(display.width() / 2 - strlen(text2) * 6 / 2, 9);
  display.println(text2);
  display.setCursor(display.width() / 2 - strlen(text3) * 6 / 2, 18);
  display.println(text3);

  display.display();                // Need this command to refresh screen
  tone(sidetonePin, 700);
  delay(50);
  noTone(sidetonePin);
}
//=============================================================================================================================================
void SetFreq(int Band, long Freq) {
  if (Band == 3) {  // If Band is 60m retrieve Channel Frequency
    Freq = ChanArray[Freq1];
  }
  
  Si.setFreq(0, Freq); //si5351mcu
  //For desired offset on RX output Clk2
  //long RXFreq = Freq + DESIRED OFFSET;
  //For Quadrature RX i.e. QRPLabs RX Module, offset is chosen offset * 4
  long RXFreq = (Freq *4) -2000;
  Si.setFreq(2, RXFreq);
  Si.enable(2);
}
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
void loop() {

  Display_Freq(Freq1);

  if (Freq1 != oldFreq) {
    Display_Freq(Freq1);
    SetFreq(Band, Freq1);
    oldFreq = Freq1;
  }

  Check_SPOT_Status();  //check if SPOT button pressed

  // Get keyer speed
  speed = analogRead(keySpeed);         // Read the keying speed from potmeter
  speed = map(speed, 0, 1023, 35, 10);  //was 57,17
  DOTLEN = (1200 / speed);
  DASHLEN = (3 * (1200 / speed));

  // Get Battery voltage
  voltageDivider = analogRead(A2);                  // Read the level of one third of supply voltage via voltage divider
  voltage = ((voltageDivider * (4.2 / 1023.0)) * 3);  // Convert the analog reading (which goes from 0 - 1023) to a voltage (0 - 12.6V) for a 3S battery

  // Keyer code

  if (!digitalRead(intKey))  // If the internal straight key is presssed..
  {
    STRAIGHTKEYER();
  }

  if (straightKey == false)  //Paddle connected
  {

    if (!digitalRead(paddleDot))  // If the dot lever is presssed..
    {
      dit();  // ... send a dot at the given speed
    }

    if (!digitalRead(paddleDash))  // If the dash lever is pressed...
    {
      dash();  // ... send a dash at the given speed
    }
  }

  if (straightKey == true)  //Straight key in use
  {
    if (!digitalRead(paddleDot))  // If the dot lever is presssed..
    {
      STRAIGHTKEYER();
    }
  }

  // Check if Rotary Encoder pressed
  currentState = digitalRead(PinSW);

  if (lastState == HIGH && currentState == LOW) {  // button is pressed
    pressedTime = millis();
  } else if (lastState == LOW && currentState == HIGH) {  // button is released
    releasedTime = millis();

    long pressDuration = releasedTime - pressedTime;

    if (pressDuration < SHORT_PRESS_TIME) {
      if (Band == 3) {                   // If Band is 60m
        deltaFreq = !deltaFreq;          // toggle deltaFreq between 0 and 1
      } else if (bandChanged == true) {  //do band filter switching here after a band has been selected
        deltaFreq = 100;                 // set intial tune step to 100Hz on band change
        for (int i = 8; i <= 12; i++) {
          digitalWrite(i, HIGH);
        }
        digitalWrite(LPFPinArray[Band], LOW);
        bandChanged = false;
      } else {                // If Band is not 60m and band has not been changed, toggle frequency steps
        switch (deltaFreq) {  // increment frequency step
          case 0: deltaFreq = 10000; break;
          case 10: deltaFreq = 0; break;
          case 100: deltaFreq = 10; break;
          case 1000: deltaFreq = 100; break;
          case 10000: deltaFreq = 1000; break;
        }
      }
    }

    if (pressDuration > LONG_PRESS_TIME) {
     while ((digitalRead(paddleDot)) && (digitalRead(intKey))) { //repeat CQ until left paddle or straight / internal key is pressed
      if (millis() - timeNow >= timeInterval) { //timeInterval set to 4 seconds
        sendmsg("CQ CQ CQ DE G4USI G4USI G4USI K");
        timeNow = millis();
      }
    }
  }
  }
  // save the the last state
  lastState = currentState;
}
